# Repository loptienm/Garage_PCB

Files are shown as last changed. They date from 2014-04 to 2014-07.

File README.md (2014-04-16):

Garage_PCB
==========

This is a Garage Controller that will be able to open/close the garage door, tell me when to stop pulling forward, and read garage door open/close status.  The controller will run on a Spark Core and will use a supersonic range finder to get the distance from the wall to the car bumper to tell me when to stop pulling forward, it will use a reed switch to tell if the garage door is open or not, and it will be able to interface with the garage door opener without changing any of the existing hardware.

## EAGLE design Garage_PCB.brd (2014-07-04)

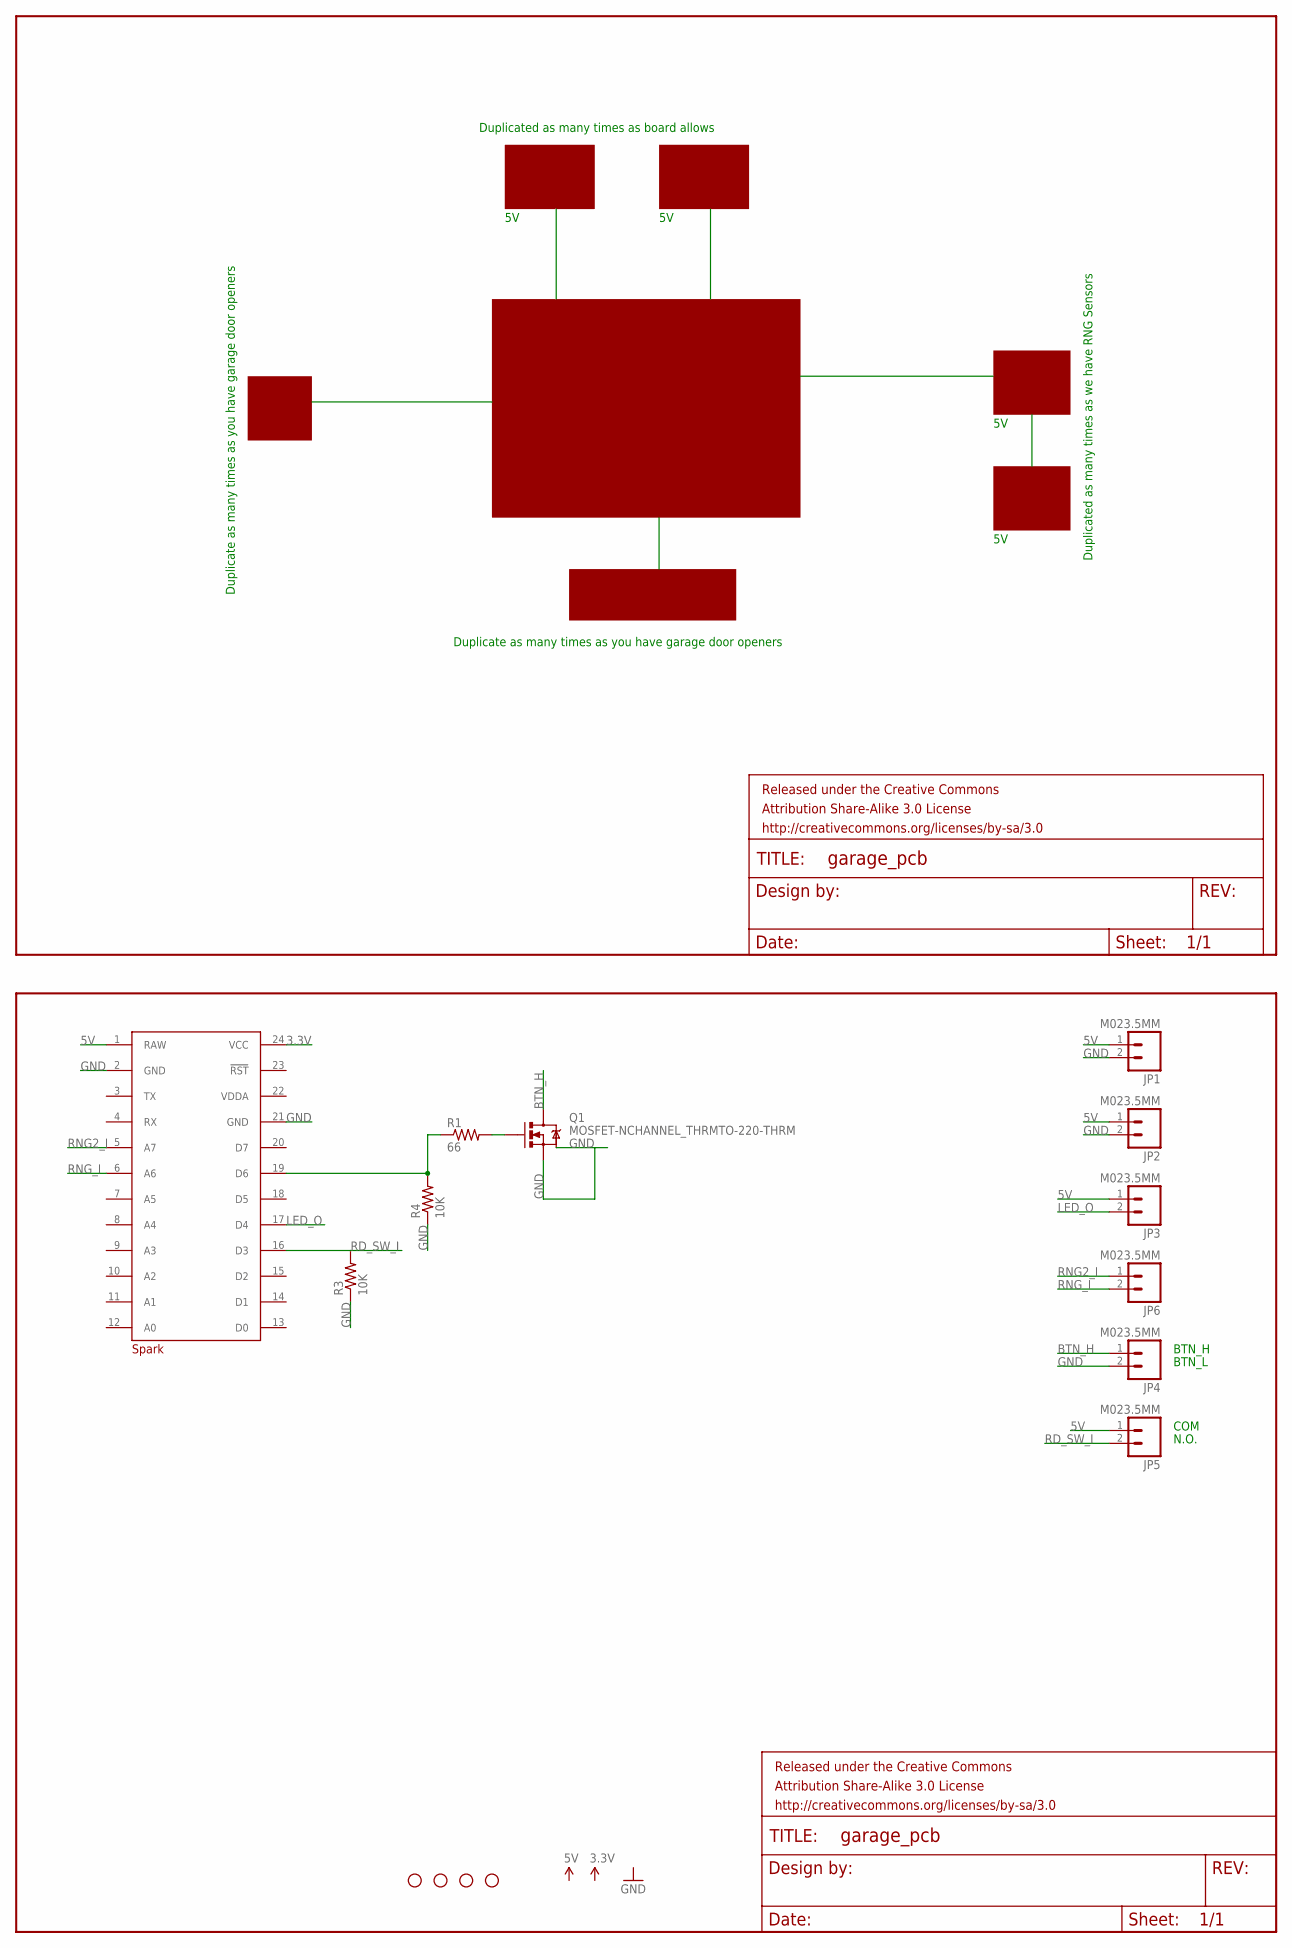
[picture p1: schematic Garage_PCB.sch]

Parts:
FRAME1, FRAME2: FRAME-LETTER; CREATIVE_COMMONS
JP1, JP2, JP3, JP4, JP5, JP6: M023.5MM; SCREWTERMINAL-3.5MM-2
Q1: MOSFET-NCHANNEL_THRMTO-220-THRM; TO220-THRM
R1: 66; 0603-RES
R3, R4: 10K; 0603-RES
SPARK: SPARK_CORECORE; SPARK_CORE
STANDOFF1, STANDOFF2, STANDOFF3, STANDOFF4: STAND-OFF
U$2: SPARK_LOGO2

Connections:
3.3V: SPARK.24 (VCC)
5V: JP1.1, JP2.1, JP3.1, JP5.1, SPARK.1 (RAW)
BTN_H: JP4.1, Q1.GND (D)
GND: JP1.2, JP2.2, JP4.2, Q1.OUT (S), Q1.THRM, R3.1, R4.1, SPARK.2 (GND), SPARK.21 (GND)
LED_O: JP3.2, SPARK.17 (D4)
unnamed: R1.1, R4.2, SPARK.19 (D6)
unnamed: Q1.IN (G), R1.2
RD_SW_I: JP5.2, R3.2, SPARK.16 (D3)
RNG2_I: JP6.1, SPARK.5 (A7)
RNG_I: JP6.2, SPARK.6 (A6)
VDDA: SPARK.22 (VDDA)

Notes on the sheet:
N.O.
COM
Duplicated as many times as board allows
Duplicated as many times as we have RNG Sensors
Duplicate as many times as you have garage door openers
BTN_L
BTN_H

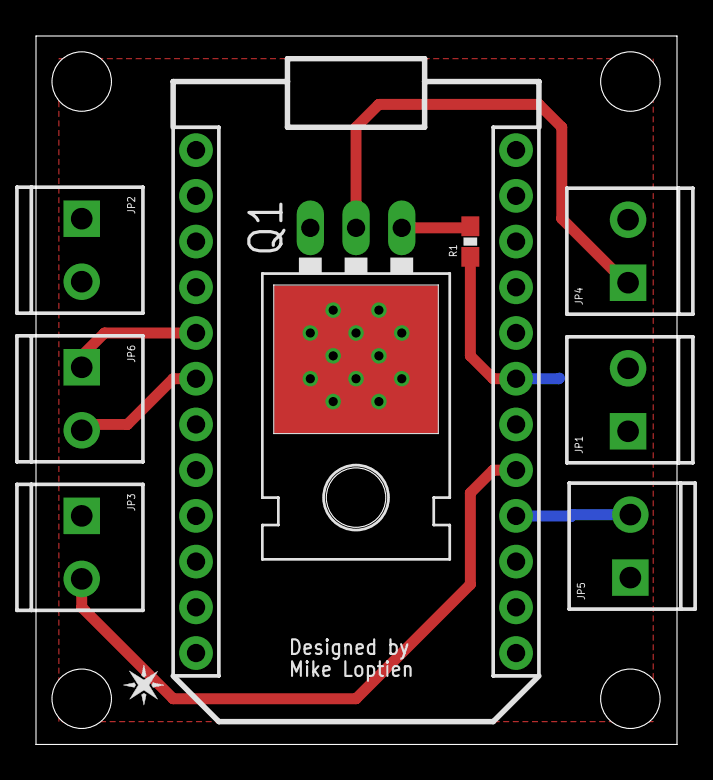
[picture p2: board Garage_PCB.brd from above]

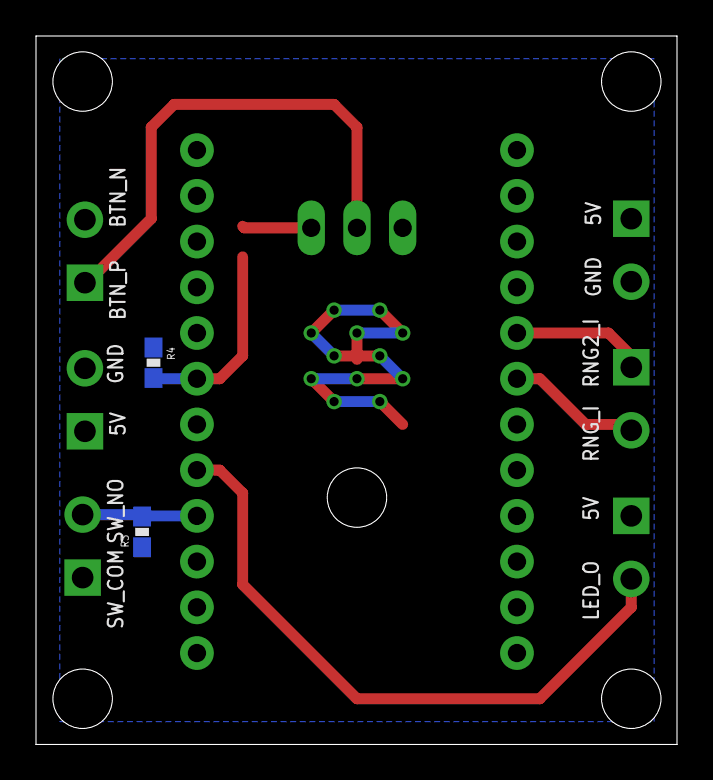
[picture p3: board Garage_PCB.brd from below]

Board: 2 copper layers, 35.6 x 39.4 mm, 18 parts (2 on the bottom side), 9 nets.

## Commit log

2014-04-16 Add initial Eagle schematic
    Add an Eagle Schematic and project file. The schematic just has a
    border and some power rails (5V, 3.3V, GND).
    [Garage_PCB.sch]
2014-04-20 Added parts, created board, placed parts and rails
    Added Spark core, 5V regulator, N-channel MOSFET for switching the 24V
    line for the garage door, and some screw terminals that I can connect to
    the Magnetic switch
    (http://www.amazon.com/Directed-Electronics-8601-Magnetic-Switch/dp/B0009SUF08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),
    a range finder (https://www.sparkfun.com/products/8503), and an RGB LED
    (https://www.sparkfun.com/products/11820). These parts will allow me to
    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
    [Garage_PCB.brd]
2014-04-20 Routed the traces
    Routed all the traces for the board. Ran a DRC and there were no
    errors.
    [Garage_PCB.brd]
2014-04-20 Changed screw terminals to 3.5mm pitch instead of 2.54mm
    These screw terminals are much less ugly but are a bit bigger. They
    still fit pretty well though.
    [Garage_PCB.brd, Garage_PCB.sch]
2014-04-20 Put 5V regulator on top layer
    Moved the regulator from the bottom layer to the top layer. It is still
    underneath the Spark but there should be plenty of room for it.
    [Garage_PCB.brd]
2014-04-20 Added my name and the Spark logo
    Added my name to the board and the Spark logo as well. Also added the
    Spark Eagle Library to the Eagle directory search paths so that I can
    edit library parts.
    [Garage_PCB.brd, Garage_PCB.sch]
2014-04-20 Moved Mosfet and shrunk design
    Moved the MOSFET underneath the Spark on the bottom layer so I can save
    some space. I moved just about everything around and was able to shrink
    the board down to basically just the size of the Spark and the extra
    width of the screw terminals. It is very small now and costs almost $4
    less to build.
    [Garage_PCB.brd, Garage_PCB.sch]
2014-06-14 Moved the Mosfet to top layer
    Moved the Mosfet to the top layer and made the necessary changes to the
    board to connect it. Also moved one of the Range finder pins to be
    closer to the other. Added a thermal pad to the Mosfet and added some
    thermal vias.
    [Garage_PCB.brd, Garage_PCB.sch]
2014-06-15 Added a pulldown to the BTN_L side
    After some breadboard testing I found that the low side of the garage
    door button needs to be pulled down to ground in order to de-energize
    the line so that a new contact successfully gets registered. Added this
    pulldown and ordered this revision of the board.
    [Garage_PCB.brd, Garage_PCB.sch]
2014-07-04 Removed MOSFET inline resistors
    The garage door button needs to have a direct connection from power
    (btn_h) to ground (btn_l) in order to open or close the garage door.
    The high side resistor kept this from happening. I am not sure what I
    was thinking with the low side 'pull down'. This was just a weird
    resistor connecting a groundplane on the opener to a ground plane on my
    board.
    I also renamed a few of the connection labels on the backside to be
    correct. The btn_p and btn_n were backwards and this was causing the
    opener to not work. The range finders also need to have different
    labels so that the user knows which one is connected for configuring the
    app/Spark Core.
    [Garage_PCB.brd, Garage_PCB.sch]

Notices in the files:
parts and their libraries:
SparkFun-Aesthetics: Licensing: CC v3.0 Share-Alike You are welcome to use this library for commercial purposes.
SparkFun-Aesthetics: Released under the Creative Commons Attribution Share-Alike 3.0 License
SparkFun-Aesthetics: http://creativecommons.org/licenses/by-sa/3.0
